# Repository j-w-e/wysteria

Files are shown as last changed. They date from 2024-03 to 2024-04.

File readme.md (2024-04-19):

# JWE's custom split keyboard, the Wysteria

This is my custom split 36-key keyboard, with an encoder knob on each hand, and a pinky cluster to avoid stretching my pinky – I find lateral movement easier.

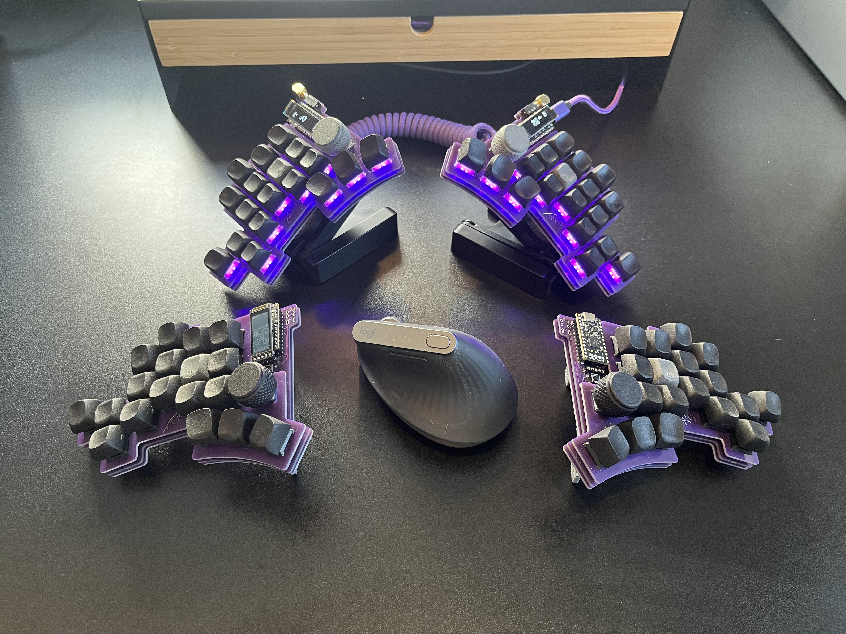
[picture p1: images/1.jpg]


The pcbs, and the source ergogen file used to generate v0.3, can be found in the pcbs folder.

It has working firmware for both QMK and ZMK. Source files are in the repo, but I have not put this into the main repos for either QMK or ZMK. My own build process symlinks these as appropriate.

## NOTES
v0.3 has been printed and tested, and is my current daily driver. However, please note that to build it, the diodes on the thumb cluster need to be handwired to the rows. The traces on the PCB itself are incorrect. This has been fixed in the ergogen config file, ready for if and when I print it again, but this has not had all the traces set up in KiCad, and has not been printed or tested.

* Will (should) work with both QMK (with an oled and trrs) and ZMK (with nice!nano and nice!view)
* If using a display, make sure to solder the jumpers _on the opposite side_ of the board to where the dislay is mounted. This is different to the MCU jumpers, which should be soldered on the same side as the MCU (if mounting face-up)
* The ergogen config places an extra diode below the middle finger, bottom row. I manually replace this in KiCad with the Wysteria graphic. (I haven't worked out how to make the graphic into an ergogen-compatible footprint. I'm happy with the manual step for now.)

## Parts used
* [Liatris](https://splitkb.com/collections/keyboard-parts/products/liatris) or [nice!nano](https://splitkb.com/collections/keyboard-parts/products/nice-nano)
* [OLED displays](https://www.aliexpress.com/item/32850288143.html?spm=a2g0o.order_list.order_list_main.40.77df1802Ut4SVX) or [nice!view](https://splitkb.com/collections/keyboard-parts/products/nice-view)
* [Sockets](https://www.aliexpress.com/item/32980406694.html?spm=a2g0o.order_list.order_list_main.5.21ef1802pi0AaX)
* [Batteries](https://www.aliexpress.com/item/4000377326948.html?spm=a2g0o.order_list.order_list_main.29.77df1802Ut4SVX) for wireless builds
* [Reset switches](https://www.aliexpress.com/item/32912263133.html?spm=a2g0o.order_list.order_list_main.15.21ef1802pi0AaX)
* [Hotswap sockets](https://www.aliexpress.com/item/1005003873653184.html?spm=a2g0o.order_list.order_list_main.21.21ef1802pi0AaX)
* [Power switches](https://www.aliexpress.com/item/1005003308186629.html?spm=a2g0o.order_list.order_list_main.26.21ef1802pi0AaX) for wireless builds
* [Socket pins](https://www.aliexpress.com/item/4000062247368.html?spm=a2g0o.order_list.order_list_main.31.21ef1802pi0AaX)
* [Diodes](https://www.aliexpress.com/item/32660088529.html?spm=a2g0o.order_list.order_list_main.5.21ef1802a9afJe)
* [EC11](https://www.aliexpress.com/item/1005003824684681.html?spm=a2g0o.cart.0.0.5d5838daGifwXE&mp=1)
* [EC11 knob](https://github.com/GEIGEIGEIST/KLOR/tree/main/knob) from GEIST
* [M2 screws](url)
* Switches and keycaps (all 1u). My current set-up has [Boba U4](https://splitkb.com/collections/switches-and-keycaps/products/gazzew-boba-u4-silent-tactile-switch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) in the office, [Boba U4Tx](https://splitkb.com/collections/switches-and-keycaps/products/gazzew-boba-u4tx-thocky-tactile-switch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) at home, and [DES](https://github.com/sporkus/PseudoMakeMeKeyCapProfiles/tree/master/stl/MX) printed by JLCPCB

### Tenting set-up

* [Z-fold tripod](https://www.aliexpress.com/item/1005006313678530.html)
* [Magsafe tripod adapter](https://www.aliexpress.com/item/1005006074567830.html)
* [Folding laptop stands](https://www.temu.com/goods.html?_bg_fs=1&goods_id=601099538883858&_x_sessn_id=7odffn4414)

## To do

If I ever decide to build a new one, want to:

* ~~Fix the problem of the thumb cluster not being in the matrix~~
* Move the thumb keys slightly further down (ie closer to the wrist). My thumbs naturally rest so that only the very tip is on the key.
* Rotate the lateral pinky key by 90 degrees, so that the keycap can be rotated as well.
* Move the lateral pinky key down 2mm.
* Move the reset switch to a more sensible location, though where that is I don't currently know.
* If I am feeling very ambitious, think about making a steel plate as a base, so it attaches cleanly to the magsafe tripod adapter. But I would need to work out how to properly countersink the screws, and rethink where the screws are.

## References

Made based on
* [ergogen](https://github.com/ergogen/ergogen)
* [FlatFootFox's ergogen intro](https://flatfootfox.com/ergogen-introduction/)
* [TSteffek's guide to ergogen v4 compared to v3](https://github.com/tsteffek/Ergogen-V4-Migration-Guide)
* Kvietcong's fork of [ergogen](https://github.com/kvietcong/ergogen) (for the footprints)
* Ceoloide's [corney-island](https://github.com/ceoloide/corney-island)
* Narkoleptika's [josukey](https://github.com/Narkoleptika/josukey)

### Guides for other parts

### Keyboards used as reference
* [Rae-dux](https://github.com/andrewjrae/rae-dux) (especially the build guide from [tzcl](https://www.tzcl.me/blog/rae-dux) for parts references)
* [Claw](https://gitlab.com/Audijo/keyboard) (for ergogen)
* [Piano](https://github.com/benvallack/ergogen/blob/master/input/config-piano.yaml)
* [PicaChoc36](https://github.com/zzeneg/picachoc36) (eg for parts references)
* [Swoop](https://github.com/jimmerricks/swoop) (eg for parts references)
* [Klor](https://github.com/GEIGEIGEIST/KLOR/blob/main/docs/buildguide_acrylic_ble.md)
* [Sofle](https://josefadamcik.github.io/SofleKeyboard/sourcing_parts.html)

### Other references:
* Sadek Baroudi's [guide to making cases](https://github.com/sadekbaroudi/keyboard-guides/blob/master/cases/README.md)
* Ben Vallack's [video on using ergogen](https://www.youtube.com/watch?v=M_VuXVErD6E) (nb: outdated as it is based on ergogen v3)
* [Batteries](https://github.com/joric/nrfmicro/wiki/Batteries#301230)
* The Absolem [build guide](https://zealot.hu/absolem/#build)

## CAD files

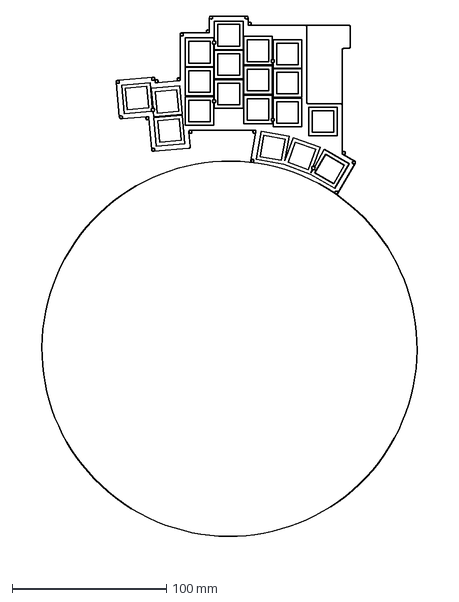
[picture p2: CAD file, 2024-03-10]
ergogen/output/outlines/preview.dxf
276.5 x 353.9 mm

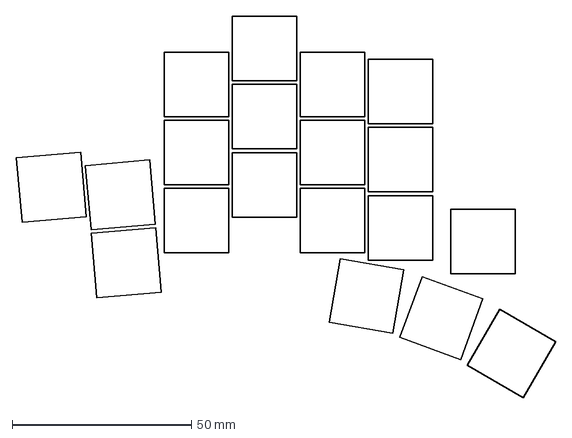
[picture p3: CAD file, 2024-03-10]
ergogen/output/points/demo.dxf
150.5 x 106.4 mm

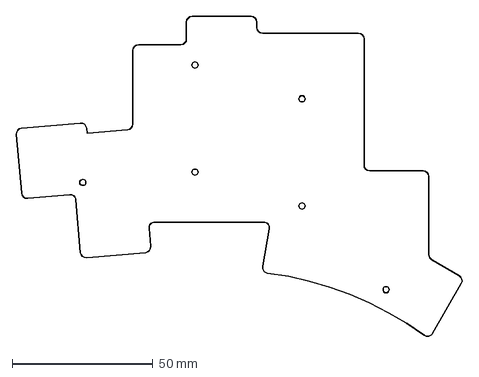
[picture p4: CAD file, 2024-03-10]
ergogen/output/outlines/_plate.dxf
158.5 x 113.6 mm

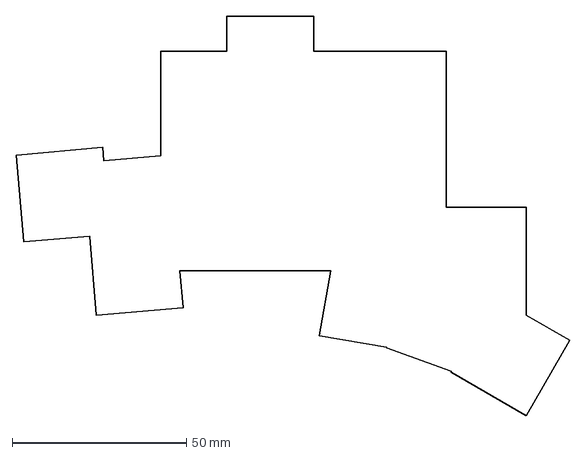
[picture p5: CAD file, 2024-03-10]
ergogen/output/outlines/_raw.dxf
159.0 x 114.7 mm

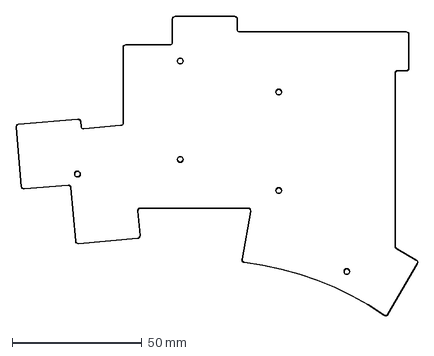
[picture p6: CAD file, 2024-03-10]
ergogen/output/outlines/board.dxf
155.2 x 115.5 mm

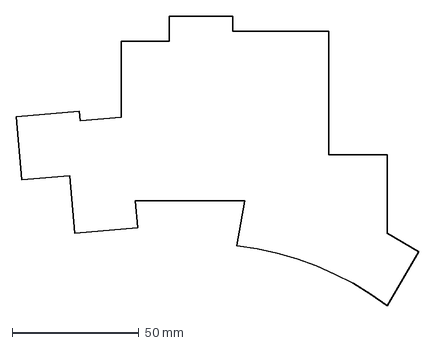
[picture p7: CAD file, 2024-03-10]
ergogen/output/outlines/_composite_without_controller.dxf
159.0 x 114.5 mm

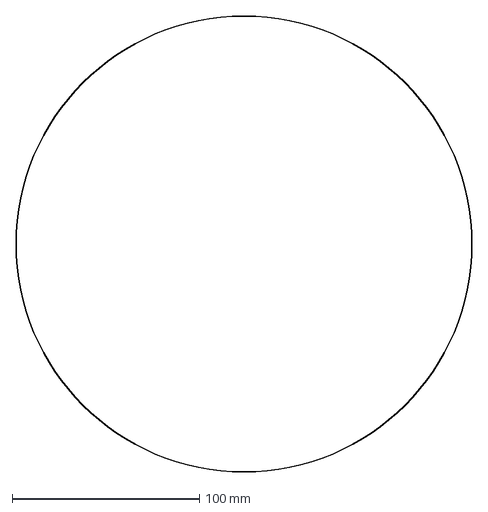
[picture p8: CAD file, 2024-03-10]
ergogen/output/outlines/_circ_thumb.dxf
243.2 x 243.2 mm

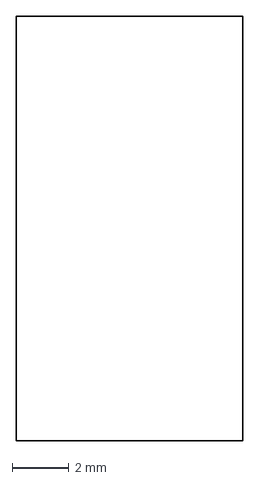
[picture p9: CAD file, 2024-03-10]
ergogen/output/outlines/_trrs.dxf
8.00 x 15.0 mm

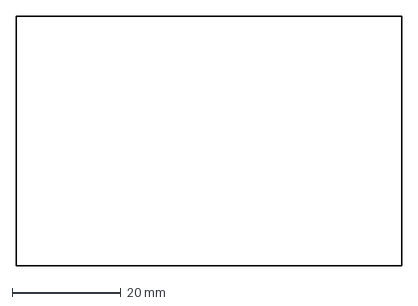
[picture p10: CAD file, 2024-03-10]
ergogen/output/outlines/_controller2.dxf
71.0 x 46.0 mm

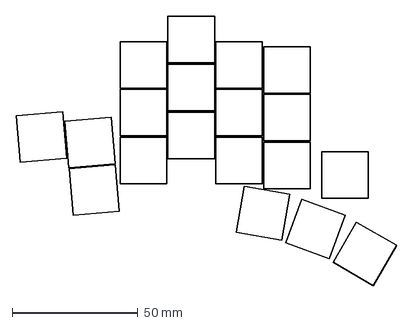
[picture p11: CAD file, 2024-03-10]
ergogen/output/outlines/_keys.dxf
151.1 x 107.0 mm

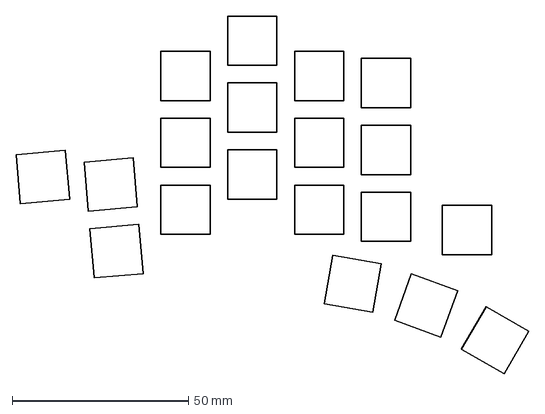
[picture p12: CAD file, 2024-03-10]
ergogen/output/outlines/_switch_cutouts.dxf
145.6 x 101.6 mm

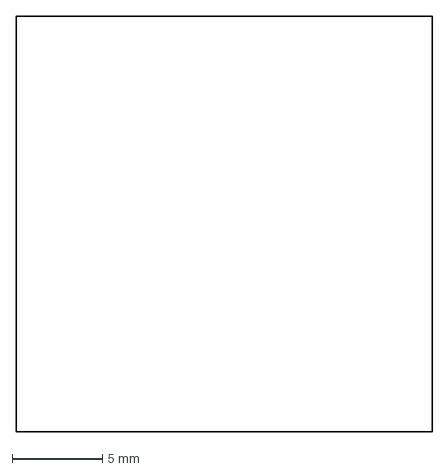
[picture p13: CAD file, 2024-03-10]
ergogen/output/outlines/_extension_for_index.dxf
23.0 x 23.0 mm

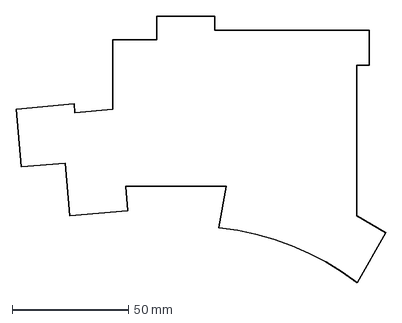
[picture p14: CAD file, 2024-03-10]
ergogen/output/outlines/_composite_with_controller.dxf
159.0 x 114.5 mm

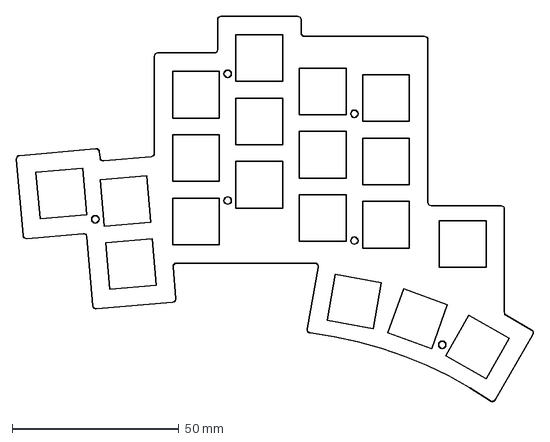
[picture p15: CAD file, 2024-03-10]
ergogen/output/outlines/switch_plate.dxf
155.2 x 115.5 mm

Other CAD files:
ergogen/output/outlines/_controller1.dxf
ergogen/output/outlines/_extension_for_inner.dxf
ergogen/output/outlines/_screws.dxf

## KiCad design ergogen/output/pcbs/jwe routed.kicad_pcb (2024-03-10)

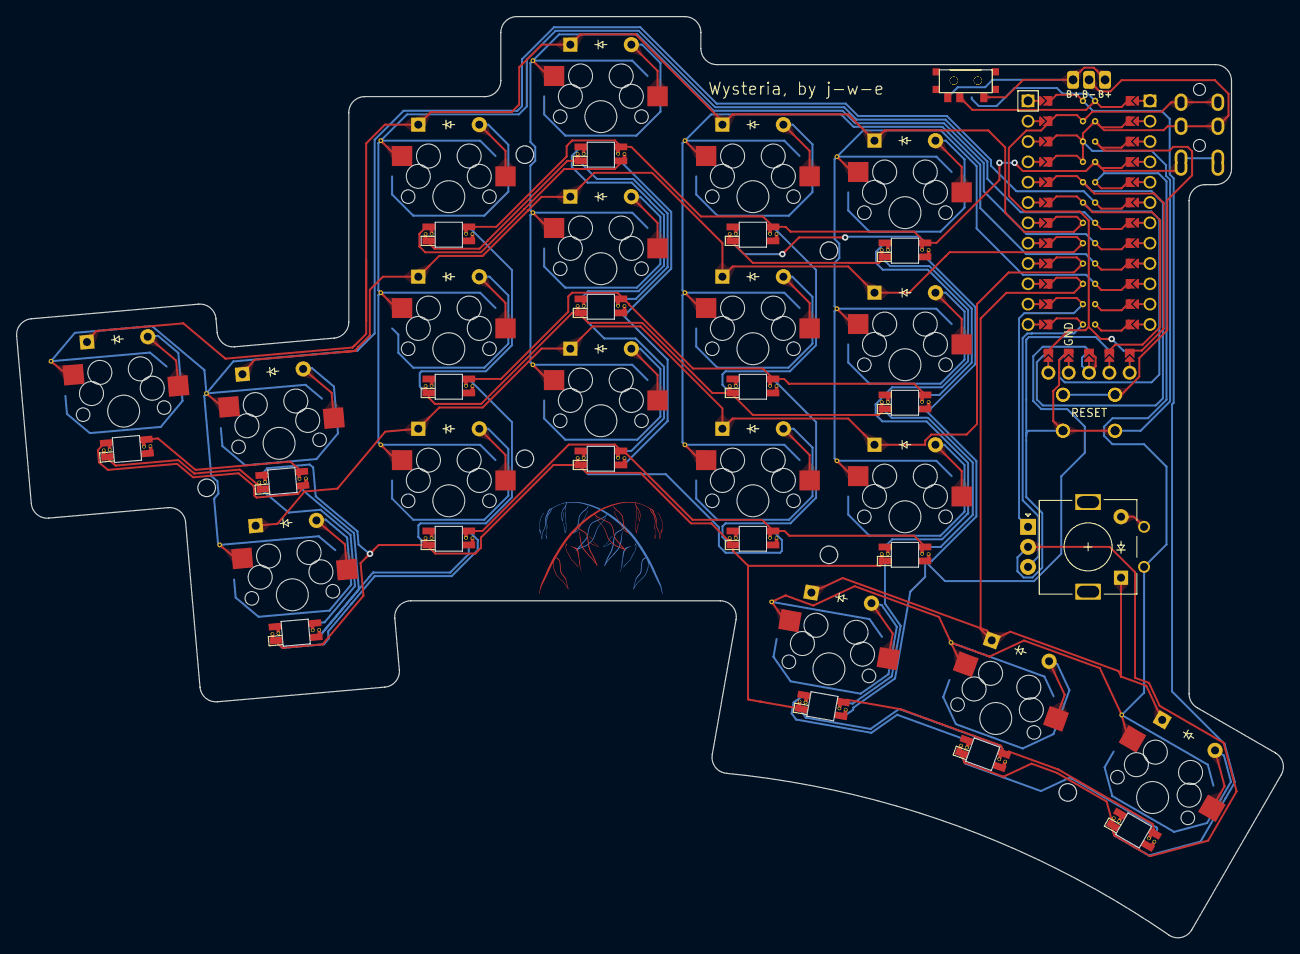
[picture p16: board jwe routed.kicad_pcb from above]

Board: 2 copper layers, 158.3 x 115.1 mm, 66 parts (1 on the bottom side), 57 nets.

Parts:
B1, B2: SW_TACT_ALPS_SKQGABE010
D1, D2, D3, D4, D5, D6, D7, D8, D9, D10, D11, D12, D13, D14, D15, D16, D17, D18, D19: ComboDiode
D20, D20#2: Wysteria
JST1: bat
L9, L9#2, L9#3, L9#4, L9#5, L9#6, L9#7, L9#8, L9#9, L9#10, L9#11, L9#12, L9#13, L9#14, L9#15, L9#16, L9#17, L9#18: SK6812Mini-e; WS2812B
ROT1: rotary_encoder
S1, S2, S3, S4, S5, S6, S7, S8, S9, S10, S11, S12, S13, S14, S15, S16, S17, S18: MX
SCREEN1: combo_display
T1, T2: SPDT_C128955
TRRS1: TRRS-PJ-320A-dual
_1: ProMicro

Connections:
GND: B1.2, B2.2, JST1.2, L9.3, L9#2.3, L9#3.3, L9#4.3, L9#5.3, L9#6.3, L9#7.3, L9#8.3, L9#9.3, L9#10.3, L9#11.3, L9#12.3, L9#13.3, L9#14.3, L9#15.3, L9#16.3, L9#17.3, L9#18.3, ROT1.C, SCREEN1.1, TRRS1.3, _1.2, _1.21, _1.22
LED_1: L9#6.2, L9#17.4
LED_2: L9.4, L9#17.2
LED_3: L9.2, L9#9.4
LED_4: L9#9.2, L9#11.4
LED_5: L9#7.4, L9#11.2
LED_6: L9#7.2, L9#14.4
LED_7: L9#4.4, L9#14.2
LED_8: L9#4.2, L9#12.4
LED_9: L9#5.4, L9#12.2
LED_10: L9#5.2, L9#15.4
LED_11: L9#8.4, L9#15.2
LED_12: L9#8.2, L9#13.4
LED_13: L9#13.2, L9#18.4
LED_14: L9#16.4, L9#18.2
LED_15: L9#3.4, L9#16.2
LED_16: L9#2.4, L9#3.2
LED_17: L9#2.2, L9#10.4
RAW: T1.2, T2.2, _1.1
RST: B1.1, B2.1, _1.3
VCC: L9.1, L9#2.1, L9#3.1, L9#4.1, L9#5.1, L9#6.1, L9#7.1, L9#8.1, L9#9.1, L9#10.1, L9#11.1, L9#12.1, L9#13.1, L9#14.1, L9#15.1, L9#16.1, L9#17.1, L9#18.1, SCREEN1.2, TRRS1.1, TRRS1.2, _1.4
bat: JST1.1, T1.1, T2.1
c_index: S10.2, S11.2, S12.2, _1.9
c_inner: S13.2, S14.2, S15.2, _1.10
c_middle: S7.2, S8.2, S9.2, _1.8
c_pinkie: S1.2, S2.2, S3.2, _1.6
c_ring: S4.2, S5.2, S6.2, _1.7
c_thumb: ROT1.2, S16.2, S17.2, S18.2, _1.5
central_home: D17.2, S17.1
data: SCREEN1.5, TRRS1.4, _1.23
index_bottom: D10.2, S10.1
index_home: D11.2, S11.1
index_top: D12.2, S12.1
inner_bottom: D13.2, S13.1
inner_home: D14.2, S14.1
inner_top: D15.2, S15.1
led: L9#6.4, _1.24
middle_bottom: D7.2, S7.1
middle_home: D8.2, S8.1
middle_top: D9.2, S9.1
mosi: SCREEN1.4, SCREEN1.5, _1.20
pinkie_bottom: D1.2, S1.1
pinkie_home: D2.2, S2.1
pinkie_top: D3.2, S3.1
r_bottom: D1.1, D4.1, D7.1, D10.1, D13.1, _1.16
r_home: D2.1, D5.1, D8.1, D11.1, D14.1, _1.17
r_thumb: D16.1, D17.1, D18.1, D19.1, _1.15
r_top: D3.1, D6.1, D9.1, D12.1, D15.1, _1.18
ring_bottom: D4.2, S4.1
ring_home: D5.2, S5.1
ring_top: D6.2, S6.1
rot_anticlock: ROT1.B, _1.13
rot_clock: ROT1.A, _1.14
rotary_key: D19.2, ROT1.1
sck: SCREEN1.3, _1.19
stretchie_home: D18.2, S18.1
tuckie_home: D16.2, S16.1

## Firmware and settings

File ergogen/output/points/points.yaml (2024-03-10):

main_pinkie_bottom:
    x: 117.0506184
    'y': -190.5233653
    r: 5
    meta:
        stagger: 0
        spread: 19
        splay: 0
        origin:
            - 0
            - 0
        orient: 0
        shift:
            - 0
            - 0
        rotate: 0
        adjust: {}
        width: 18
        height: 18
        padding: 19
        autobind: 10
        skip: false
        asym: both
        colrow: pinkie_bottom
        name: main_pinkie_bottom
        bind:
            - 1
            - 1
            - 1
            - 1
        tags:
            alphas: true
        col_net: c_pinkie
        row_net: r_bottom
        key: &ref_0
            led_prev: LED_15
            led_next: LED_16
        zone: &ref_3
            key:
                padding: ky
                spread: kx
                tags:
                    alphas: true
            rows:
                bottom:
                    row_net: r_bottom
                home:
                    row_net: r_home
                top:
                    row_net: r_top
            columns:
                pinkie: &ref_1
                    key:
                        col_net: c_pinkie
                    rows:
                        top:
                            adjust:
                                shift: &ref_4
                                    - '-kx'
                                    - '-0.8ky'
                            key: &ref_5
                                led_prev: LED_17
                                led_next: LED_18
                        home:
                            key: &ref_2
                                led_prev: LED_16
                                led_next: LED_17
                        bottom:
                            key: *ref_0
                    name: pinkie
                ring: &ref_7
                    key:
                        splay: -5
                        stagger: 10
                        spread: 20.5
                        col_net: c_ring
                        bind:
                            - b
                            - b
                            - b
                            - b
                    rows:
                        top:
                            key: &ref_9
                                led_prev: LED_12
                                led_next: LED_13
                        home:
                            key: &ref_8
                                led_prev: LED_13
                                led_next: LED_14
                        bottom:
                            key: &ref_6
                                led_prev: LED_14
                                led_next: LED_15
                    name: ring
                middle: &ref_11
                    key:
                        stagger: 10
                        col_net: c_middle
                    rows:
                        top:
                            key: &ref_13
                                led_prev: LED_11
                                led_next: LED_12
                        home:
                            key: &ref_12
                                led_prev: LED_10
                                led_next: LED_11
                        bottom:
                            key: &ref_10
                                led_prev: LED_9
                                led_next: LED_10
                    name: middle
                index: &ref_15
                    key:
                        stagger: -10
                        col_net: c_index
                        bind:
                            - b
                            - b
                            - b
                            - kx
                    rows:
                        top:
                            key: &ref_17
                                led_prev: LED_6
                                led_next: LED_7
                        home:
                            key: &ref_16
                                led_prev: LED_7
                                led_next: LED_8
                        bottom:
                            key: &ref_14
                                led_prev: LED_8
                                led_next: LED_9
                    name: index
                inner: &ref_19
                    key:
                        stagger: -2
                        bind:
                            - b+2
                            - b
                            - ky
                            - b
                        col_net: c_inner
                    rows:
                        top:
                            key: &ref_21
                                led_prev: LED_5
                                led_next: LED_6
                        home:
                            key: &ref_20
                                led_prev: LED_4
                                led_next: LED_5
                        bottom:
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

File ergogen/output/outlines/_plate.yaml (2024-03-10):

models:
    export:
        models:
            a:
                models:
                    a:
                        models: {}
                        origin:
                            - 0
                            - 0
                    b:
                        models:
                            a:
                                models:
                                    a:
                                        models:
                                            a:
                                                models:
                                                    a:
                                                        models: {}
                                                        origin:
                                                            - 0
                                                            - 0
                                                    b:
                                                        models:
                                                            a:
                                                                models:
                                                                    a:
                                                                        models:
                                                                            a:
                                                                                models:
                                                                                    a:
                                                                                        models:
                                                                                            a:
                                                                                                models:
                                                                                                    a:
                                                                                                        models:
                                                                                                            a:
                                                                                                                models:
                                                                                                                    a:
                                                                                                                        models:
                                                                                                                            a:
                                                                                                                                models:
                                                                                                                                    a:
                                                                                                                                        models:
                                                                                                                                            a:
                                                                                                                                                models:
                                                                                                                                                    a:
                                                                                                                                                        models:
                                                                                                                                                            a:
                                                                                                                                                                models:
                                                                                                                                                                    a:
                                                                                                                                                                        models:
                                                                                                                                                                            a:
                                                                                                                                                                                models:
                                                                                                                                                                                    a:
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
